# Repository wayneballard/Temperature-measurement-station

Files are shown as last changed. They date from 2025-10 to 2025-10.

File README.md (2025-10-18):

## About

The simplest temperature measurement station was built during this project, all the necessary and detailed information is in [pdf](./Report.pdf) file.


## Key results

- System performs cyclic, synchronous measurement of process value (controlled variable) with
constant sample time.
- System allows for process control in safe range of process value.
- System ensures steady-state error at 5% of the control range
- System allows to set a reference value (set-point) with serial port
- System allows reading current values of: measurement, reference and control signals with serial
port

## Hardware and software

The project was completed using STM32CubeIDE version 1.16.1 on NUCLEO development kit with the STM32F746ZG microcontroller + Temrinal app which communicates through UART.

## IMPORTANT

For better performance it is suggested to use higher power supply(I used 9V battery which turned out not to be enough) and retune gains. In my case the PID controller is very sluggish.

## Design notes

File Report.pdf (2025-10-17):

# POZNAŃ UNIVERSITY OF TECHNOLOGY

## FACULTY OF CONTROL, ROBOTICS AND ELECTRICAL ENGINEERING

## INSTITUTE OF ROBOTICS AND MACHINE INTELLIGENCE

## DIVISION OF CONTROL AND INDUSTRIAL ELECTRONICS

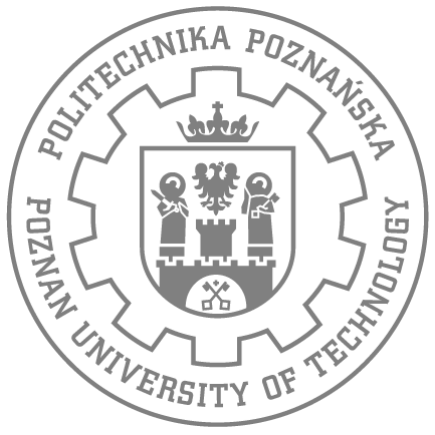
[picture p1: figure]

# FINAL TASK: TEMPERATURE MEASUREMENT

# SYSTEM WITH FEEDBACK

# MICROPROCESSOR SYSTEMS

### LABORATORY REPORT

### IVAN IATSENKO, 157566

IVAN1.IATSENKO@PUT.POZNAN.PL

## HAITHEM LADJ, 156006

HAITHEM.LADJ@PUT.POZNAN.PL»

### INSTRUCTOR:

ADRIAN WÓJCIK, M.SC.

ADRIAN.WOJCIK@PUT.POZNAN.PL

28-01-2025

Microprocessor systems: «Laboratory exercise»
Poznań University of Technology, Institute of Robotics and Machine Intelligence, Division of Control and Industrial Electronics

### INTRODUCTION

The system introduced in this report is a simplest temperature measurements system with feedback control.

Software: STM32CubeIDE, Matlab, Python.

Hardware: STM32 Nucleo board, BC517 Darlington Transistor, 2x 100 ohm resistors, breadboard, wires, heating resistor, BMP280 sensor.

## TASK #1

1.1 SPECIFICATION

As we have a feedback, to properly take advantage of it, any type of controller should be introduced to the system. In our case it is PI, which should control the system in the steady-state. The system should allow us to read actual data, reference value, PI action and give a setpoint to the system.

1.2 IMPLEMENTATION

Firstly, the circuit(Fig. 1) was built on the breadboard, the connection of pins responsible for communication between sensor and MCU is presented in Tab 1.

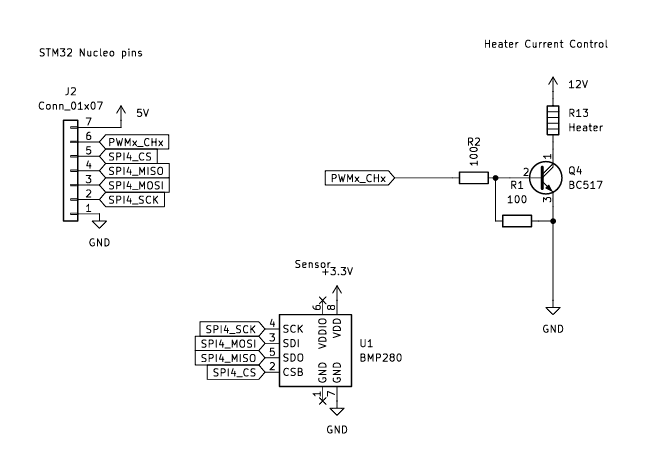
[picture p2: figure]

Fig 1. Schematic in KiCad EDA

NUCLEO-F746ZG | BH1750
Pin # | Pin name | Pin # | Pin name
--PE2 PE6 PE4 PE5 | 3V3 GND SAI_A SAI_A SAI_A SAI_A | 1 2 3 4 5 6 | VCC GND SCL SDA CSB SDO

Tab. 1 BMP280 digital light sensor connection to NUCLEO-F746ZG via SPI

Then, the raw data from the sensor(9 V power supply, 2.5 V on the heater) was collected using a Python script, which was created by professor Luczak(Listing 1). The response is presented in Fig 2.

#@author Dominik Łuczak

# @date 2021-11-19

import serial #pip install pyserial import numpy as np
from time import sleep
import time
import json
import matplotlib.pyplot as plt import keyboard #pip install keyboard

plt.ion()
hSerial = serial.Serial('COM3', 9600, timeout=1, parity=serial.PARITY_NONE) hSerial.write(b'PWM1=90;')
sleep(0.5)
hSerial.write(b'freq=1;')
sleep(0.5)

timestr = time.strftime("%Y%m%d-%H%M%S") hFile = open("data_%s.txt" % (timestr), "a")

hSerial.reset_input_buffer() hSerial.flush()
temperature_samples = [];
t = [];
t_value=0;
while True:
text = hSerial.readline()
temperature = 0
sample = 0
try:
| sample = json.loads(text) temperature = sample["temp"]

except ValueError:
| print("Bad JSON") print("%s\r\n" % {text}) hSerial.flush() hSerial.reset_input_buffer()

print(temperature)
hFile.write("%.2f," % temperature) temperature_samples.append(temperature);

t.append(t_value);
t_value = t_value + 1
# Plot results

plt.clf()
plt.plot(t,temperature_samples, '.', markersize=5);
plt.title("BMP280 logger, STM32 (SPI,UART,JSON). (author: D. Łuczak)") plt.xlabel("Time (s)")
plt.ylabel("Temperature (C)")
plt.show()
plt.pause(0.0001)
if keyboard.is_pressed("q"): break # finishing the loop hSerial.close()
hFile.close()
Listing 1. Sсript for registering sensor data

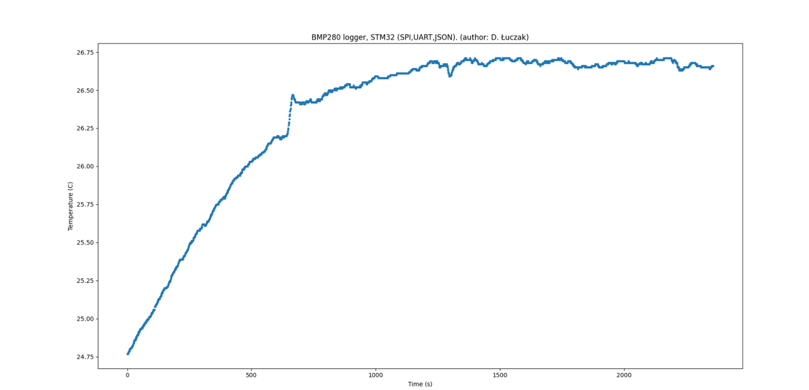
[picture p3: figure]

Fig 2. Raw data from BMP280 sensor

After, the proper model was computed in MATLAB(Listing 2, Fig 3.) and simulated(Fig 4, Fig 5). The saturation block was put to the diagram with values 0 and 1 to assume full closure and full opening of transistor which control the actual circuit.

measurements = readmatrix("measurements.txt")
Ts = 1;
input_amplitude = 0.9 %assumed to be 90 percent of PWM duty cycle
samples = length(measurements);
input = input_amplitude*ones(1 , samples); %create input for linear simulation t = (0:samples-1)*Ts %time vector creation
s = tf('s');
plot(measurements)
hold on;
k = 2.2/input_amplitude
T = 330
H = k/(1+s*T)*exp(-s*20);
model = lsim(H, input, t); model = model + 24.5 %offset plot(model)

Listing 2 Model derivation in MATLAB

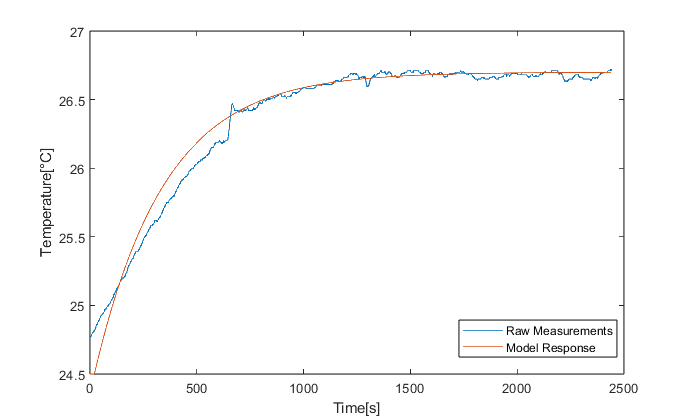
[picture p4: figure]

Fig 3. Model Response + Actual Raw data plot in MATLAB

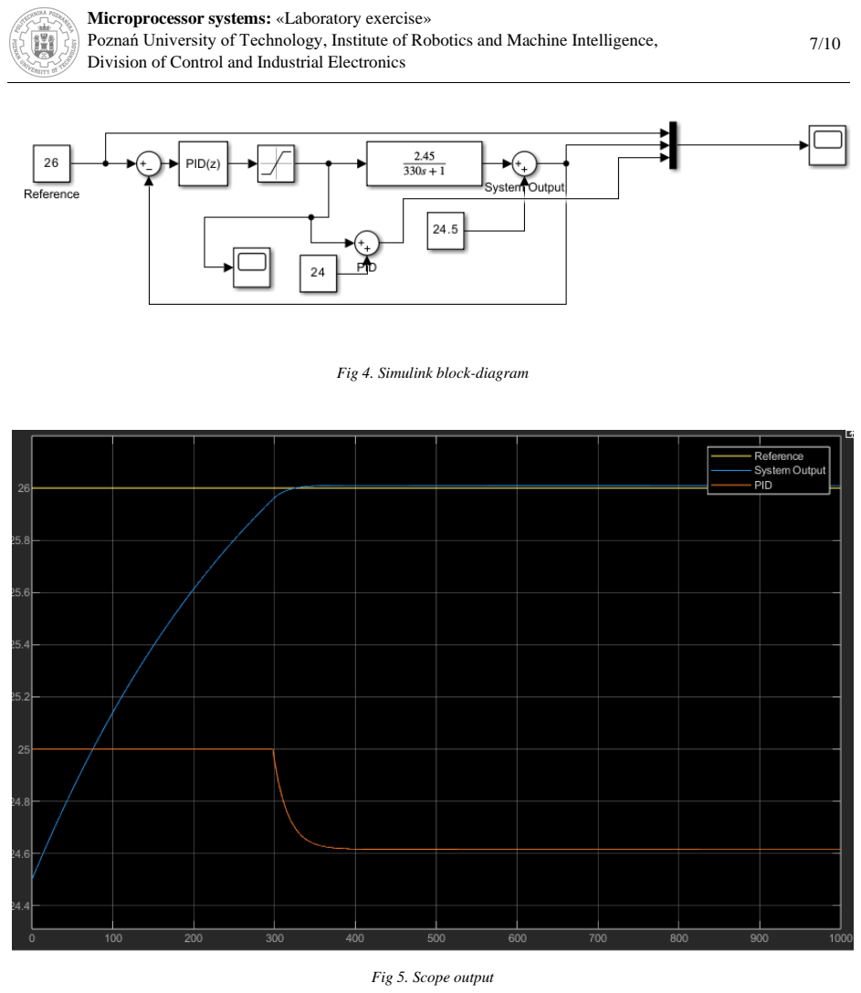
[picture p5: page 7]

Fig 4. Simulink block-diagram

Fig 5. Scope output

PWM Channel was setup with the following parameters(Fig.6):

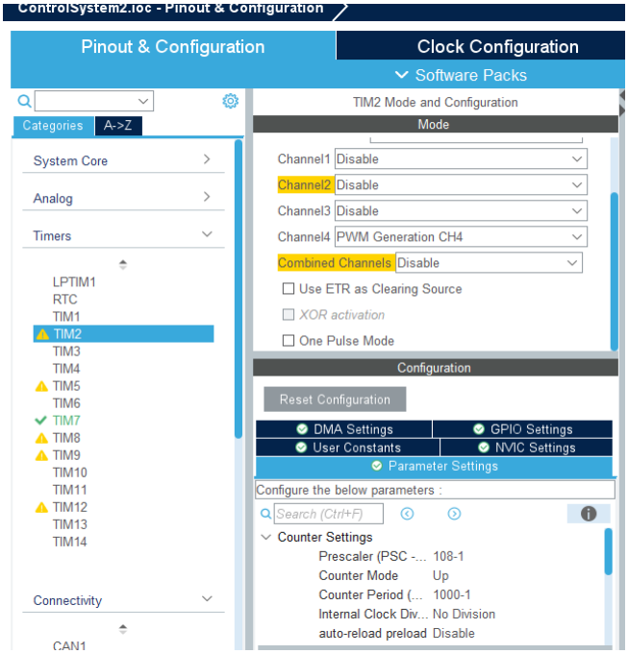
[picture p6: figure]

Fig 6. TIM2 Setup in ioc file

In order to write the data to the Terminal, write routine was implemented(Listing 3):

01. int _write(int file, char *ptr, int len)
02. {
03. return (HAL_UART_Transmit(&huart3, (uint8_t*)ptr, len, HAL_MAX_DELAY) == HAL_OK) ? len : -1;
04. }
Listing 3 Private User Code: Write Routine

In order to read the data from the Terminal(Listing 4),read routine was implemented(buffer is 8 byte array and message length is 4):

05. void HAL_UART_RxCpltCallback(UART_HandleTypeDef *huart)
06. {
07. if(huart == &huart3)
08. {
09. HAL_UART_Receive_IT(&huart3, tx_buffer, tx_msg_len);
010. }
011.}
Listing 4 Private User Code: Receive routine

In the main loop, the input setpoint is converted from char to float variable, temperature readings and parameters from the pid1 list then passed to the function. The value returned within the function assigned to a variable which controls PWM signal on TIM2(Listing 5).

012./* USER CODE BEGIN WHILE */
013. while (1)
014. {
015.
016.
017. setpoint = atof((char*)&tx_buffer[0]);
018. temp_degC = BMP2_ReadTemperature_degC(&bmp2dev)
019.
020. HAL_Delay(1000);
021. float pwm_duty_f = CalculatePID(&pid1, setpoint, temp_degC)); //calculate pid parameters and
assign to the variable
022. //handle limits
023. uint16_t pwm_duty = 0;
024. if(pwm_duty_f < 0) pwm_duty = 0;
025. else if(pwm_duty_f > 999) pwm_duty = 999;
026. else pwm_duty = (uint16_t)pwm_duty_f;
027.
028. __HAL_TIM_SET_COMPARE(&htim2, TIM_CHANNEL_4, pwm_duty);
029. printf("{\"id\":1,\"temp\":%5.2f \"Setpoint\": %5.2f \"PID\": %5.2f }\r\n",
030. | temp_degC ,setpoint, pwm_duty_f); | //set pid parameters as pwm value
031. /* USER CODE END WHILE */
032.
033. /* USER CODE BEGIN 3 */
034. }
035. /* USER CODE END 3 */ 036.

Listing 5 Program main loop: software PWM current control through the heater

10/
10

And the function itself looks in the following way(Listing 6):

037.float32_t CalculatePID(PID* pid, float32_t setpoint, float32_t value_measured) {
038. float32_t u = 0, P, I, D, error, integral, derivative;
039. error = setpoint - value_measured;
040. P = pid -> params.Kp*error;
041.
042. integral = pid -> previous_integral + (error + pid -> previous_error);
043. pid -> previous_integral = integral;
044. I = pid -> params.Ki*integral*(pid -> params.Ts/2.0);
045.
046. derivative = (error - pid -> previous_error);
047. pid -> previous_error = error;
048. D = pid -> params.Kd*derivative/(pid -> params.Ts); 049.
050. u = P + I + D;
051. return u;
052.}
Listing 6 pid.c: P, I, D parameters calulcation within the function

1.3 TEST RESULTS

As my PI was tested mainly with 9 V power supply, which is not enough for fast and robust control, still we can observe that it actually works – just slowly. The final tests were performed with higher voltage supply which helps to rejects On the first 10 screenshots(Link 1) we see how value goes up, however setpoint was a bit high – 28 percents, then 30 to speed it up. On the screenshot number 12 we see how the system ranges from 27.3 to 27.5 for a pretty long time. On the last two screenshots I put setpoint of 24 and the temperature starts dropping.

https://drive.google.com/drive/folders/1r0cwxMywkgysllkaIGlgzBz65c9L2fsu?usp=sharing

Link 1. Repository with test screenshots

1.4 CONCLUSION

In order to design robust controller a lot of parameters should be considered: power supply, any possible disturbances, gains. Because in our case low power supply(2.5 V at home vs 3.5 - 4 V in the laboratory) + disturbance made our system completely inoperable. It also results in a bit different model comparing to ours. However, increased power supply improved the situation and the controller started working returning feasible parameters within the function. Moreover, our system has quite sluggish transient response growing to the steady-state around 7 minutes(MATLAB SImulation) which also resuls in slow dynamics.

### SUMMARY

Though the system works and the controller does his job, the response is slow due to the reasons mentioned above.

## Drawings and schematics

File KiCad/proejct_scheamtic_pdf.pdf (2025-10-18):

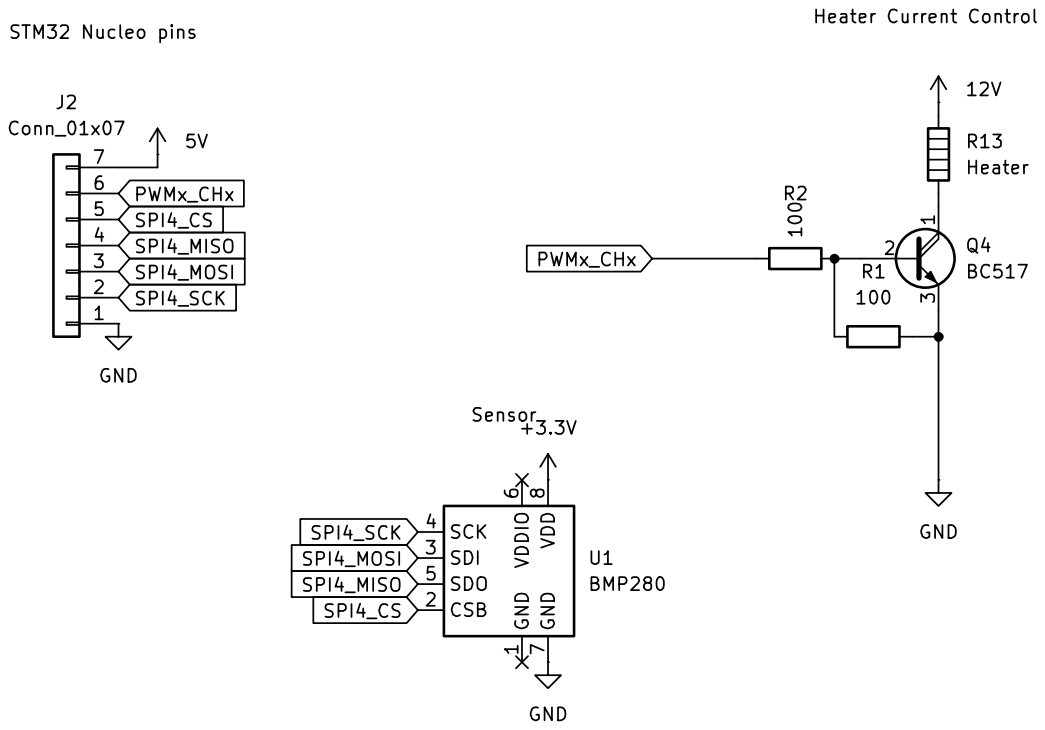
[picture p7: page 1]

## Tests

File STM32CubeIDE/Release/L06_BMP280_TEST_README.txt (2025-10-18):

PE2 (CN9) -> SCL (SCK)
PE4 (CN9) -> CB0 (CS)
PE5 (CN9) -> SDO (MISO)
PE6 (CN9) -> SDA (MOSI)

UART: 9600/8/None/2

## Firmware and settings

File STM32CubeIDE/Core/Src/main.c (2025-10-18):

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
/* Includes ------------------------------------------------------------------*/
#include "main.h"
#include "spi.h"
#include "tim.h"
#include "usart.h"
#include "gpio.h"
#include "pid.h"
/* USER CODE BEGIN Includes */



#include <stdio.h>
#include <stdlib.h>
#include "bmp2_config.h"
#include "heater_config.h"

/* USER CODE END Includes */


/* USER CODE BEGIN PV */
float setpoint = 0.0f;
float temp_degC = 0.0f;
float feedback = 0.0f;
uint8_t tx_buffer[8];
const int tx_msg_len = 4;
PID pid1 = { .params.Kp = 7, .params.Ki = 0.0035, .params.Kd = 0, .params.Ts = 1, .previous_error = 0, .previous_integral = 0};
/* USER CODE END PV */

void SystemClock_Config(void);
/* USER CODE BEGIN 0 */

int _write(int file, char *ptr, int len)
{
  return (HAL_UART_Transmit(&huart3, (uint8_t*)ptr, len, HAL_MAX_DELAY) == HAL_OK) ? len : -1;
}






void HAL_UART_RxCpltCallback(UART_HandleTypeDef *huart)
{
 if(huart == &huart3)
 {
   HAL_UART_Receive_IT(&huart3, tx_buffer, tx_msg_len);
 }
}




/* USER CODE END 0 */

/**
  * @brief  The application entry point.
  * @retval int
  */
int main(void)
{

  /* MCU Configuration--------------------------------------------------------*/

  /* Reset of all peripherals, Initializes the Flash interface and the Systick. */
  HAL_Init();

  /* Configure the system clock */
  SystemClock_Config();

  /* Initialize all configured peripherals */
  MX_GPIO_Init();
  MX_USART3_UART_Init();
  MX_SPI4_Init();
  MX_TIM2_Init();
  MX_TIM7_Init();
  /* USER CODE BEGIN 2 */


  BMP2_Init(&bmp2dev);
  HAL_UART_Receive_IT(&huart3, tx_buffer, tx_msg_len);
  /* USER CODE END 2 */

  /* Infinite loop */
  /* USER CODE BEGIN WHILE */
  while (1)
  {

    setpoint = atof((char*)&tx_buffer[0]);
    temp_degC = BMP2_ReadTemperature_degC(&bmp2dev);

    HAL_Delay(1000);
    float pwm_duty_f = (CalculatePID(&pid1, setpoint, temp_degC)); //calculate pid parameters and assign to the variable
        uint16_t pwm_duty = 0;
        //handle limits
        if(pwm_duty_f < 0) pwm_duty = 0;
        else if(pwm_duty_f > 999) pwm_duty = 999;
        else pwm_duty = (uint16_t)pwm_duty_f;

        __HAL_TIM_SET_COMPARE(&htim2, TIM_CHANNEL_4, pwm_duty); //set pid parameters as pwm value
        printf("{\"id\":1,\"temp\":%5.2f \"Setpoint\": %5.2f \"PID\": %5.2f }\r\n", temp_degC ,setpoint, pwm_duty_f);

    /* USER CODE END WHILE */

    /* USER CODE BEGIN 3 */
  }
  /* USER CODE END 3 */
}

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


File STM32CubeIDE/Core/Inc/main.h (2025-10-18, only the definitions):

#define BMP280_SPI_SCK_Pin GPIO_PIN_2
#define BMP280_SPI_SCK_GPIO_Port GPIOE
#define BMP280_SPI_CS1_Pin GPIO_PIN_4
#define BMP280_SPI_CS1_GPIO_Port GPIOE
#define BMP280_SPI_MISO_Pin GPIO_PIN_5
#define BMP280_SPI_MISO_GPIO_Port GPIOE
#define BMP280_SPI_MOSI_Pin GPIO_PIN_6
#define BMP280_SPI_MOSI_GPIO_Port GPIOE
#define USER_Btn_Pin GPIO_PIN_13
#define USER_Btn_GPIO_Port GPIOC
#define MCO_Pin GPIO_PIN_0
#define MCO_GPIO_Port GPIOH
#define RMII_MDC_Pin GPIO_PIN_1
#define RMII_MDC_GPIO_Port GPIOC
#define RMII_REF_CLK_Pin GPIO_PIN_1
#define RMII_REF_CLK_GPIO_Port GPIOA
#define RMII_MDIO_Pin GPIO_PIN_2
#define RMII_MDIO_GPIO_Port GPIOA
#define HEATER_PWM_Pin GPIO_PIN_3
#define HEATER_PWM_GPIO_Port GPIOA
#define RMII_CRS_DV_Pin GPIO_PIN_7
#define RMII_CRS_DV_GPIO_Port GPIOA
#define RMII_RXD0_Pin GPIO_PIN_4
#define RMII_RXD0_GPIO_Port GPIOC
#define RMII_RXD1_Pin GPIO_PIN_5
#define RMII_RXD1_GPIO_Port GPIOC
#define LD1_Pin GPIO_PIN_0
#define LD1_GPIO_Port GPIOB
#define RMII_TXD1_Pin GPIO_PIN_13
#define RMII_TXD1_GPIO_Port GPIOB
#define LD3_Pin GPIO_PIN_14
#define LD3_GPIO_Port GPIOB
#define STLK_RX_Pin GPIO_PIN_8
#define STLK_RX_GPIO_Port GPIOD
#define STLK_TX_Pin GPIO_PIN_9
#define STLK_TX_GPIO_Port GPIOD
#define USB_PowerSwitchOn_Pin GPIO_PIN_6
#define USB_PowerSwitchOn_GPIO_Port GPIOG
#define USB_OverCurrent_Pin GPIO_PIN_7
#define USB_OverCurrent_GPIO_Port GPIOG
#define USB_SOF_Pin GPIO_PIN_8
#define USB_SOF_GPIO_Port GPIOA
#define USB_VBUS_Pin GPIO_PIN_9
#define USB_VBUS_GPIO_Port GPIOA
#define USB_ID_Pin GPIO_PIN_10
#define USB_ID_GPIO_Port GPIOA
#define USB_DM_Pin GPIO_PIN_11
#define USB_DM_GPIO_Port GPIOA
#define USB_DP_Pin GPIO_PIN_12
#define USB_DP_GPIO_Port GPIOA
#define TMS_Pin GPIO_PIN_13
#define TMS_GPIO_Port GPIOA
#define TCK_Pin GPIO_PIN_14
#define TCK_GPIO_Port GPIOA
#define RMII_TX_EN_Pin GPIO_PIN_11
#define RMII_TX_EN_GPIO_Port GPIOG
#define RMII_TXD0_Pin GPIO_PIN_13
#define RMII_TXD0_GPIO_Port GPIOG
#define SW0_Pin GPIO_PIN_3
#define SW0_GPIO_Port GPIOB
#define LD2_Pin GPIO_PIN_7
#define LD2_GPIO_Port GPIOB

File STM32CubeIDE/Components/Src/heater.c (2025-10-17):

/*
 * heater.c
 *
 *  Created on: Jan 25, 2025
 *      Author: limok
 */

#include "heater.h"


void Heater_DIO_WriteState(const HEATER_DIO_Handle_TypeDef* hhtr, Heater_DIO_State_TypeDef state)
{
  DIO_Write(&(hhtr->Output), (hhtr->ActiveState == HEATER_ON_HIGH) ? state : !state);
}

void Heater_DIO_SetStateOn(const HEATER_DIO_Handle_TypeDef* hhtr){
  Heater_DIO_WriteState(hhtr, HEATER_ON_DIO);
}

void Heater_DIO_SetStateOff(const HEATER_DIO_Handle_TypeDef* hhtr){
  Heater_DIO_WriteState(hhtr, HEATER_OFF_DIO);
}


void Heater_DIO_ToggleState(const HEATER_DIO_Handle_TypeDef* hhtr){
  DIO_Toggle(&(hhtr->Output));
}


Heater_DIO_State_TypeDef HEATER_DIO_ReadState(const HEATER_DIO_Handle_TypeDef* hhtr){
  _Bool state = DIO_Read(&(hhtr -> Output));
    return (hhtr->ActiveState == HEATER_ON_HIGH) ? state : !state;
}

void Heater_PWM_Init(HEATER_PWM_Handle_TypeDef* hhtr){
  hhtr -> Output.Duty = (hhtr -> ActiveState == HEATER_ON_HIGH) ? (hhtr -> Output.Duty) : (100.0f - hhtr -> Output.Duty);
  PWN_Init(&(hhtr -> Output));
}


void Heater_PWM_WriteDuty(HEATER_PWM_Handle_TypeDef* hhtr, float duty){
  hhtr -> Output.Duty = (hhtr -> ActiveState == HEATER_ON_HIGH) ? (duty) : (100.0f - duty);
  PWM_WriteDuty(&(hhtr -> Output), hhtr -> Output.Duty);
}


float Heater_PWM_ReadDuty(HEATER_PWM_Handle_TypeDef* hhtr){
  return (hhtr -> ActiveState == HEATER_ON_HIGH) ? (hhtr -> Output.Duty) : (100.0f -  hhtr -> Output.Duty);
}

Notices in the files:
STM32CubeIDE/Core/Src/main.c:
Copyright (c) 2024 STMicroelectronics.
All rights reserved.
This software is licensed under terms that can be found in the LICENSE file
